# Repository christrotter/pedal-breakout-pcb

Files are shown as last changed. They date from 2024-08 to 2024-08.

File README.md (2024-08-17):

# Overview
A breakout pcb that helps make pedal wiring less nightmarish.  Intended to be used with these: https://github.com/christrotter/microswitch-pcb

I needed a cleaner way of wiring up my pedals, and now that I know how to make basic pcbs...well, for the price, hard to go back to janky prototyping boards.

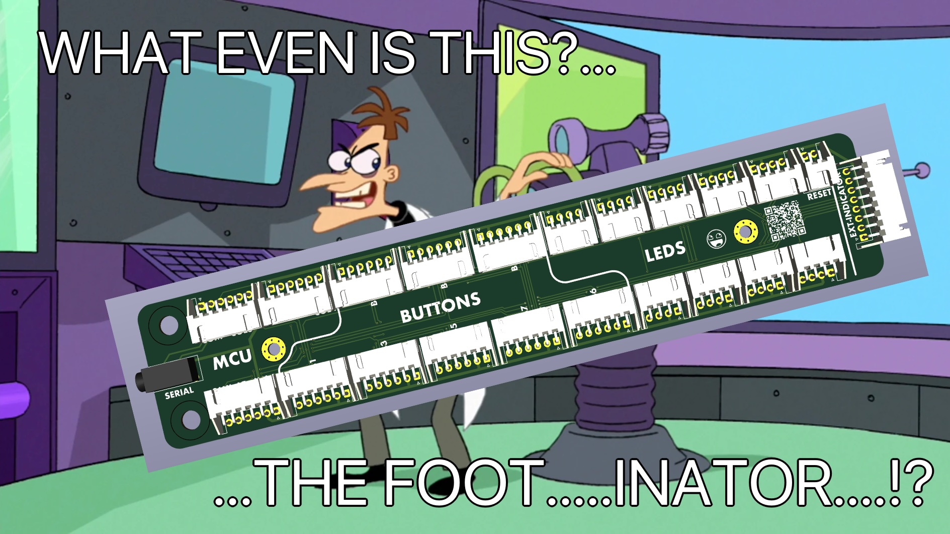
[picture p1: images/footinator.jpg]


Don't mind the renders, it's meant to utilize JST-XH horizontal connectors pointed inwards to minimize the room needed for cable routing space.
- This is meant to be super simple - just a breakout pcb
- TRRS PB-320A footprint wired up for full-duplex serial
- JST-XH 8-pin for your external indicator module
  - 2x buttons
  - LED in
  - +5V/GND
  - Reset
- 3x JST-XH 6-pin for MCU row/col, led, power/gnd, reset, serial, etc
- 1x 2-pin for reset
- 8x JST-XH 6-pin for button PCB connectivity
  - +5V/GND
  - LED IN/OUT
  - ROW & COL
- 8x JST-XH 4-pin for any internal LED necessities
  - +5V/GND
  - LED IN/OUT

I was going to do the whole nine yards and put in serial power protection and data esd, led signal up-convert, and more...but PCBA + shipping would end up being $60-80.  This design ended up being $19 shipped (_then an $8 coupon brought it down to $11 shipped_).

# Schematic
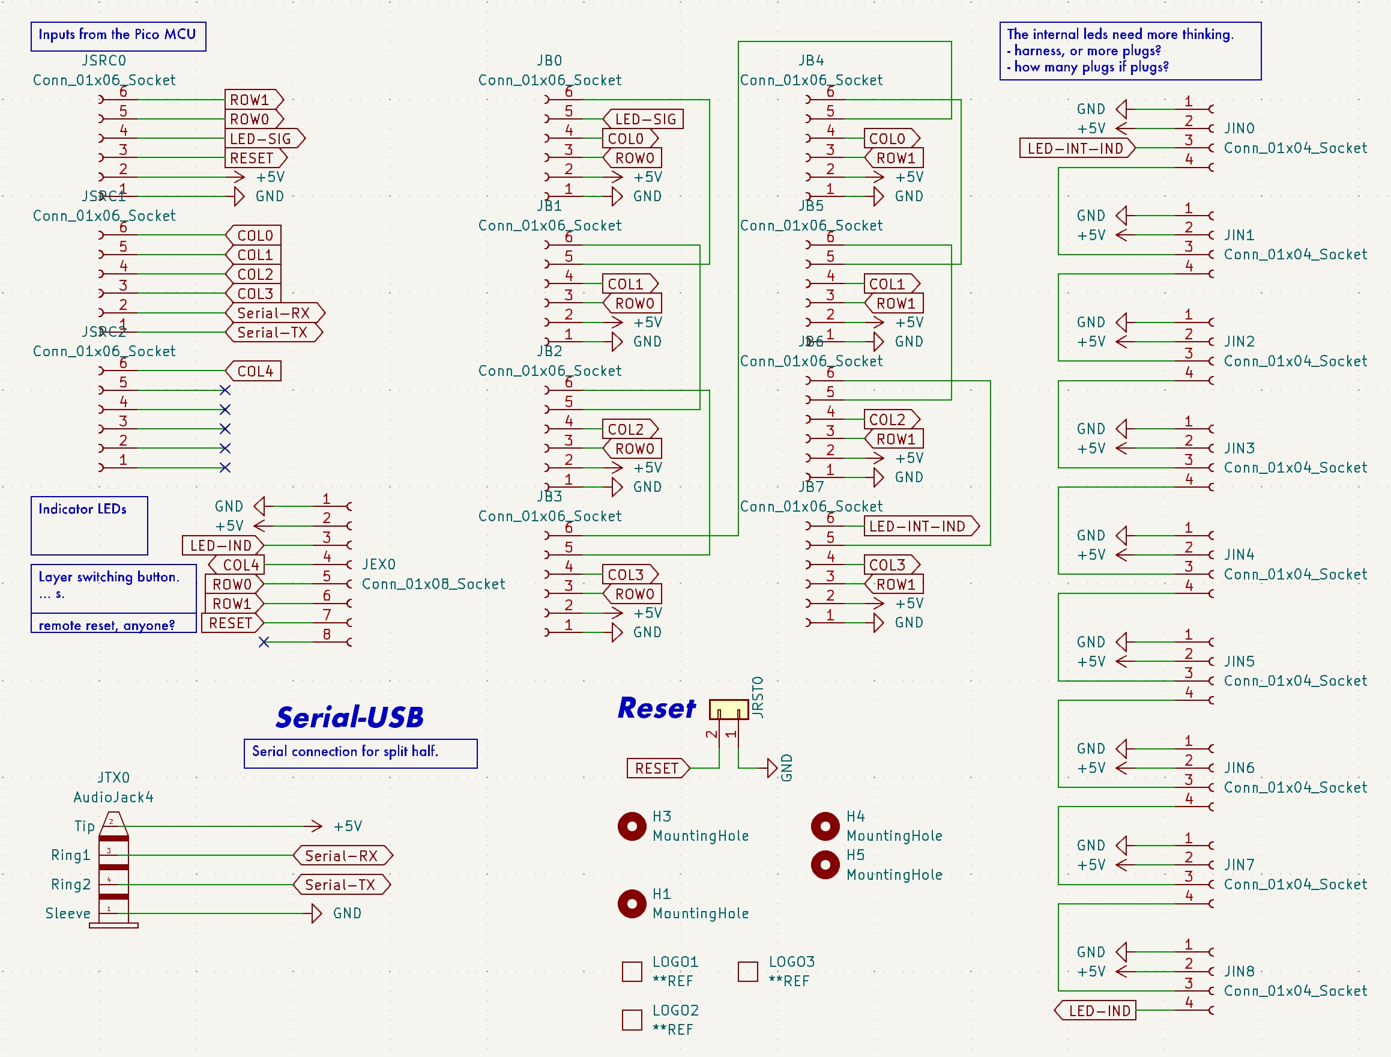
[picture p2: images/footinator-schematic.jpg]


# PCB layout
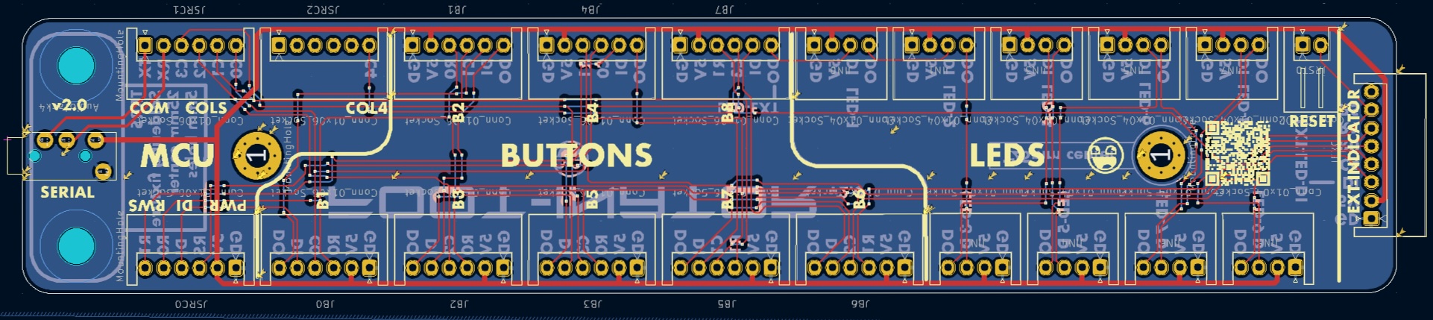
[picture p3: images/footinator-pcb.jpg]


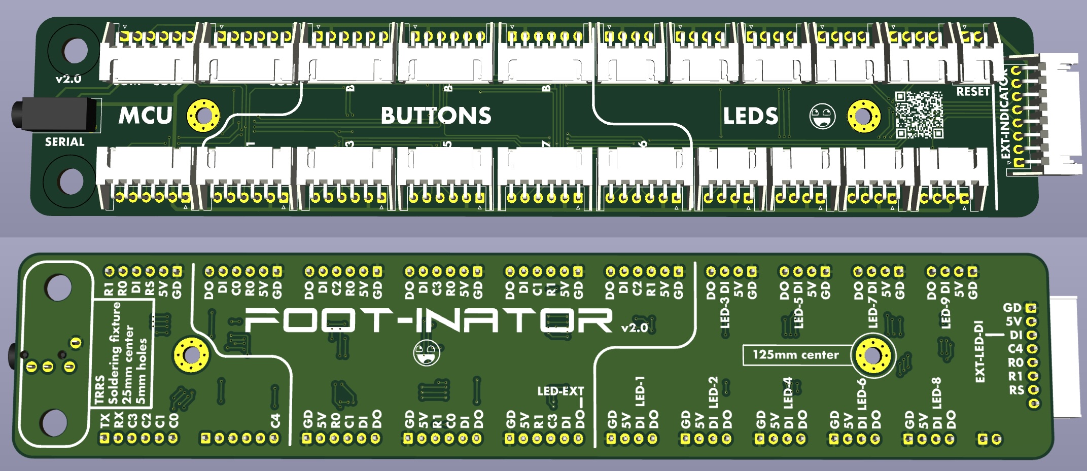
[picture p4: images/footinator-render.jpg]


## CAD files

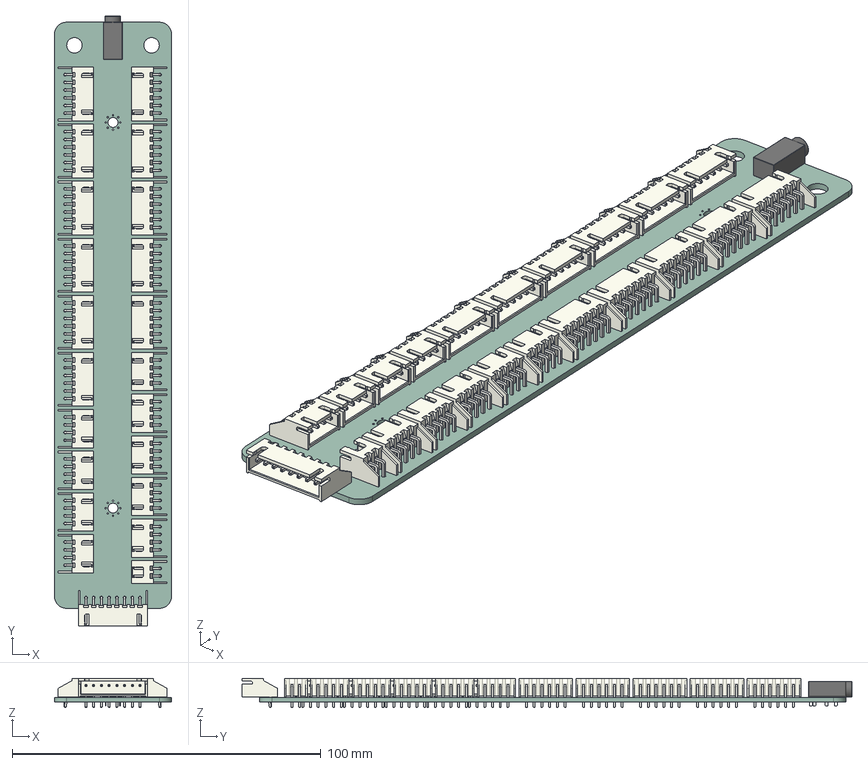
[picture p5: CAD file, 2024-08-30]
pedal-breakout-pcb.step
38.0 x 197.7 x 9.50 mm
JST_S6B_XH_A x 11
JST_S4B_XH_A x 9
JST_S8B_XH_A
JST_S2B_XH_A
PJ-3200B v1
pedal-breakout-pcb_PCB

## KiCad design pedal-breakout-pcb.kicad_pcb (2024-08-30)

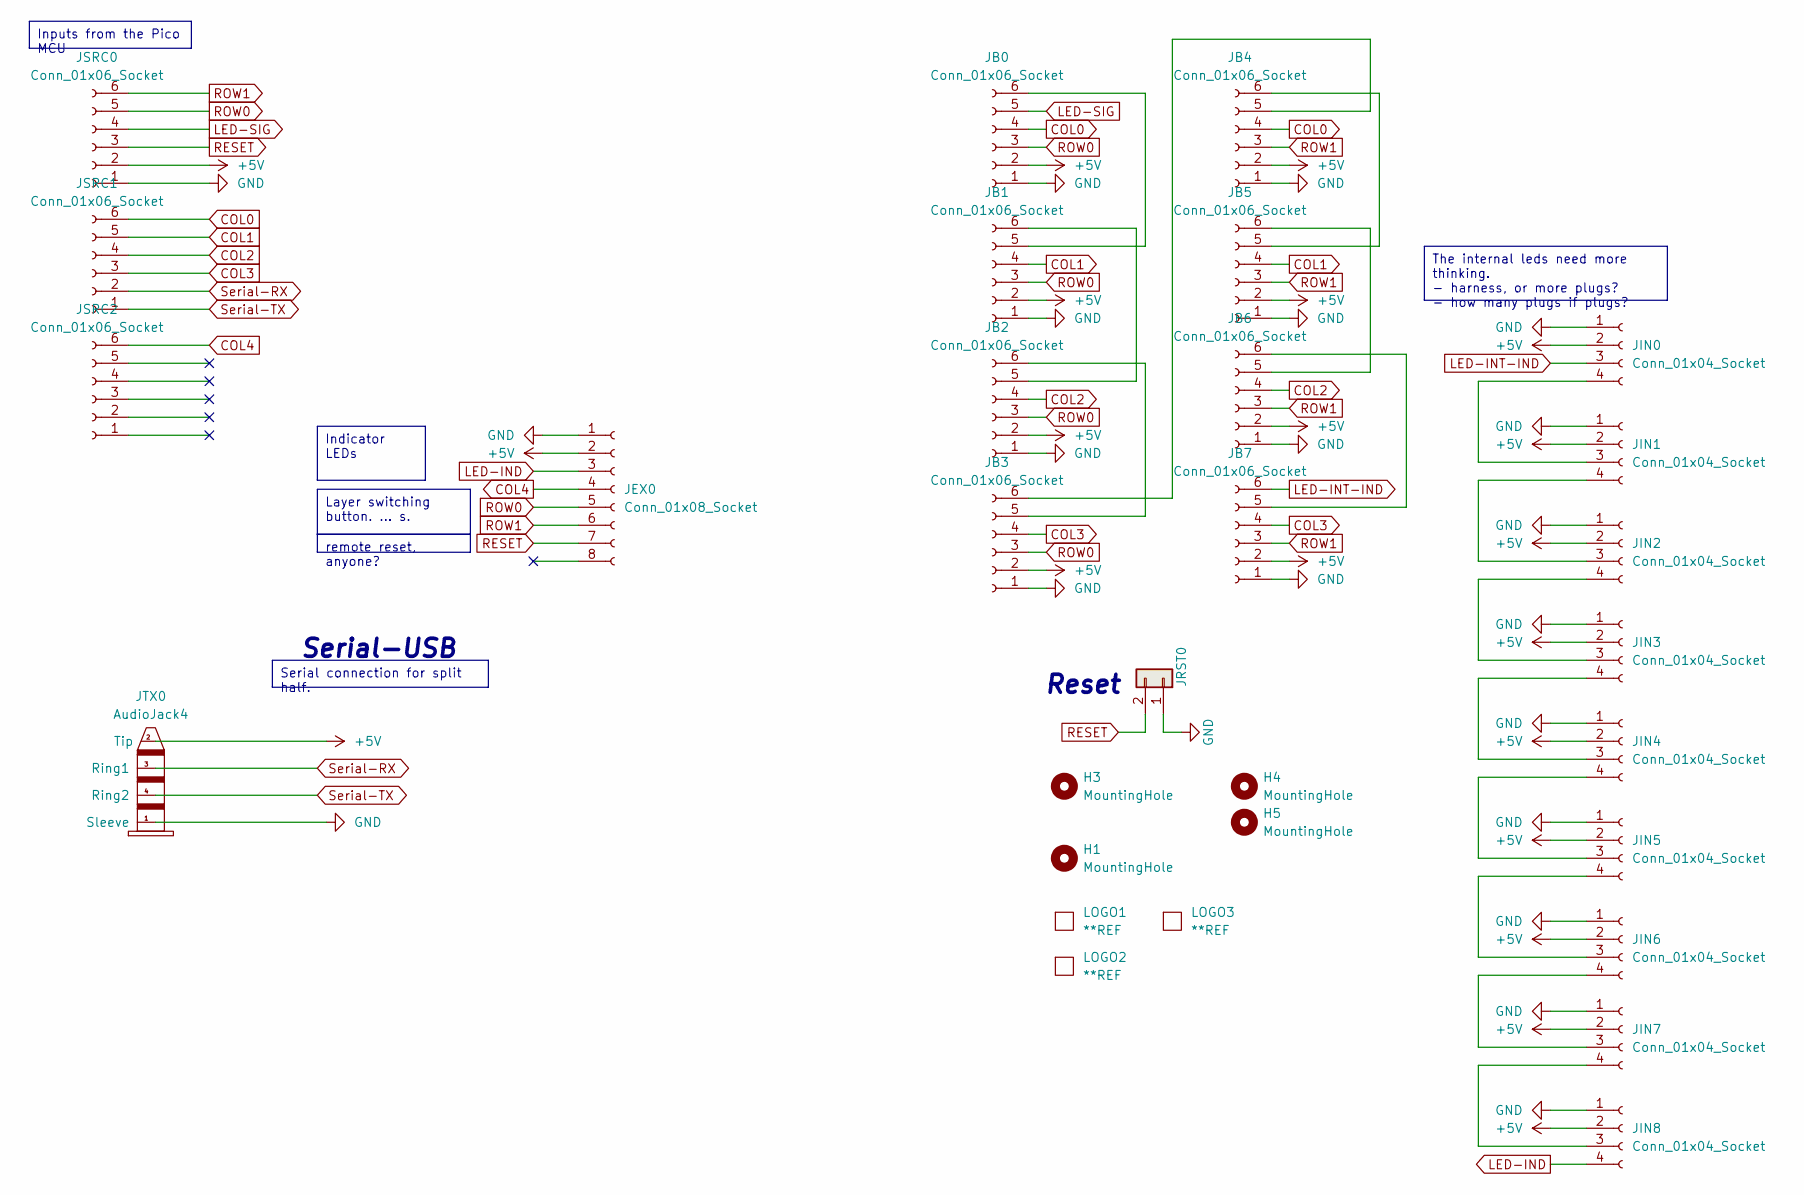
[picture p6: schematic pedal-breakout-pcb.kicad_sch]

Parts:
H1, H3: MountingHole; MountingHole_3.2mm_M3_Pad_Via
H4, H5: MountingHole; MountingHole_5mm
JB0, JB1, JB2, JB3, JB4, JB5, JB6, JB7: Conn_01x06_Socket; JST_XH_1x06_P2.50mm_Horizontal-CT
JEX0: Conn_01x08_Socket; JST_XH_1x08_P2.50mm_Horizontal-CT
JIN0, JIN1, JIN2, JIN3, JIN4, JIN5, JIN6, JIN7, JIN8: Conn_01x04_Socket; JST_XH_1x04_P2.50mm_Horizontal-CT
JRST0: Conn_01x02; JST_XH_S2B-XH-A_1x02_P2.50mm_Horizontal
JSRC0, JSRC1, JSRC2: Conn_01x06_Socket; JST_XH_1x06_P2.50mm_Horizontal-CT
JTX0: AudioJack4; PJ-320A
LOGO1, LOGO2: **REF; awesome-logo
LOGO3: **REF; pedalinator-qr-10mm

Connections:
+5V: JB0.2, JB1.2, JB2.2, JB3.2, JB4.2, JB5.2, JB6.2, JB7.2, JEX0.2, JIN0.2, JIN1.2, JIN2.2, JIN3.2, JIN4.2, JIN5.2, JIN6.2, JIN7.2, JIN8.2, JSRC0.2, JTX0.2 (Tip)
COL0: JB0.4, JB4.4, JSRC1.6
COL1: JB1.4, JB5.4, JSRC1.5
COL2: JB2.4, JB6.4, JSRC1.4
COL3: JB3.4, JB7.4, JSRC1.3
COL4: JEX0.4, JSRC2.6
GND: JB0.1, JB1.1, JB2.1, JB3.1, JB4.1, JB5.1, JB6.1, JB7.1, JEX0.1, JIN0.1, JIN1.1, JIN2.1, JIN3.1, JIN4.1, JIN5.1, JIN6.1, JIN7.1, JIN8.1, JRST0.1, JSRC0.1, JTX0.1 (Sleeve)
LED-IND: JEX0.3, JIN8.4
LED-INT-IND: JB7.6, JIN0.3
LED-SIG: JB0.5, JSRC0.4
unnamed: JB0.6, JB1.5
unnamed: JB1.6, JB2.5
unnamed: JB2.6, JB3.5
unnamed: JB3.6, JB4.5
unnamed: JB4.6, JB5.5
unnamed: JB5.6, JB6.5
unnamed: JB6.6, JB7.5
unnamed: JIN0.4, JIN1.3
unnamed: JIN1.4, JIN2.3
unnamed: JIN2.4, JIN3.3
unnamed: JIN3.4, JIN4.3
unnamed: JIN4.4, JIN5.3
unnamed: JIN5.4, JIN6.3
unnamed: JIN6.4, JIN7.3
unnamed: JIN7.4, JIN8.3
RESET: JEX0.7, JRST0.2, JSRC0.3
ROW0: JB0.3, JB1.3, JB2.3, JB3.3, JEX0.5, JSRC0.5
ROW1: JB4.3, JB5.3, JB6.3, JB7.3, JEX0.6, JSRC0.6
Serial-RX: JSRC1.2, JTX0.3 (Ring1)
Serial-TX: JSRC1.1, JTX0.4 (Ring2)

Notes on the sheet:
Serial connection for split half.
The internal leds need more thinking. - harness, or more plugs? - how many plugs if plugs?
Layer switching button. ... s.
remote reset, anyone?
Inputs from the Pico MCU
Indicator LEDs
Reset
Serial-USB

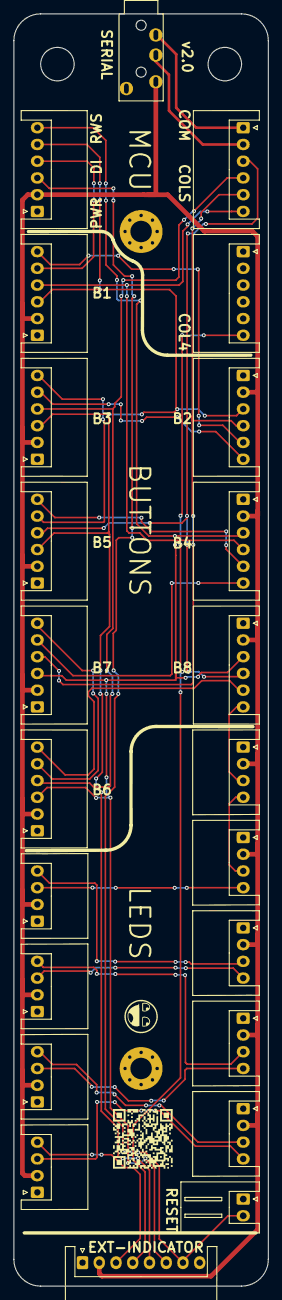
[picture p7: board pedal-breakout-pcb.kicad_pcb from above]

Board: 2 copper layers, 38.0 x 190.0 mm, 30 parts (1 on the bottom side), 30 nets.

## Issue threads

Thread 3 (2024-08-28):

first revision

christrotter, 2024-08-28:
Rev1 problems...

- logo2 ref on silkscreen
- the footprints on one half are correct, the other half will result in wiring harnesses that are backwards; footprint needs to be 180'd
- there is precious little space between the 8-pin jst and trrs jack

christrotter, 2024-08-31:
Fixed in https://github.com/christrotter/pedal-breakout-pcb/pull/4

Closed 2024-08-31.

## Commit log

2024-08-17 adding project and step files
    [pedal-breakout-pcb.kicad_pcb, pedal-breakout-pcb.kicad_sch, pedal-breakout-pcb.step]
2024-08-30 version2 files
    [pedal-breakout-pcb.kicad_pcb, pedal-breakout-pcb.kicad_sch, pedal-breakout-pcb.step]
